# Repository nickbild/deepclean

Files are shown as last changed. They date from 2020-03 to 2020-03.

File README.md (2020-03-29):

# Deep Clean

Deep Clean watches a room and flags all surfaces as they are touched for special attention on the next cleaning to help prevent the spread of contagious disease.

One use case would be in a hospital room.  When a patient checks out, the cleaning service could view all surfaces that need special attention.

<p align="center">
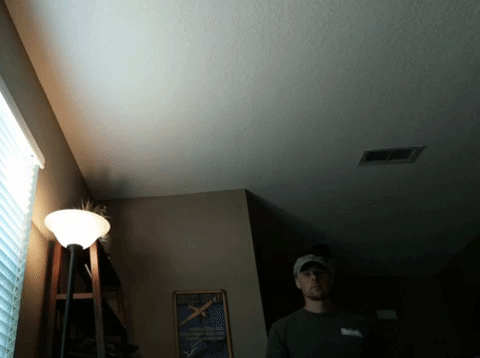
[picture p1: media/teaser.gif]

</p>

## How it Works

Deep Clean uses a stereo camera to detect the depth (z-coordinate) of an object of interest (e.g. a hand) in the video frame.  OpenPose is used to detect hand location (x,y-coordinates).  When a hand is at the same position and depth as another object in view (i.e. touching), that location is tracked.  An image can be generated showing all surfaces that have been touched ([script](https://github.com/nickbild/deepclean/blob/master/3dcam.py)).

### Camera

Camera options for the Xavier tend to be on the expensive side for a hobbyist, so I built my own from a pair of Raspberry Pi cameras.  To keep the cameras in the proper relative positions, I designed and 3D printed a [base](https://github.com/nickbild/deepclean/blob/master/3d_models/stero_cam_base.stl) and a [stabilizer](https://github.com/nickbild/deepclean/blob/master/3d_models/stereo_stabilizer.stl).

The Xavier does not have CSI connections for this type of camera, so I used a pair of Raspberry Pis to capture images ([script](https://github.com/nickbild/deepclean/blob/master/remote_cam.py)) when triggered via GPIO from the Xavier.  This is far from optimal, and shows itself in the low frame rate, but it works adequately on a budget.

The cameras were [calibrated](https://github.com/nickbild/deepclean/blob/master/camera_calibration/stereo_calibration.py) (individually, and in pair) in OpenCV using a printed chessboard pattern:

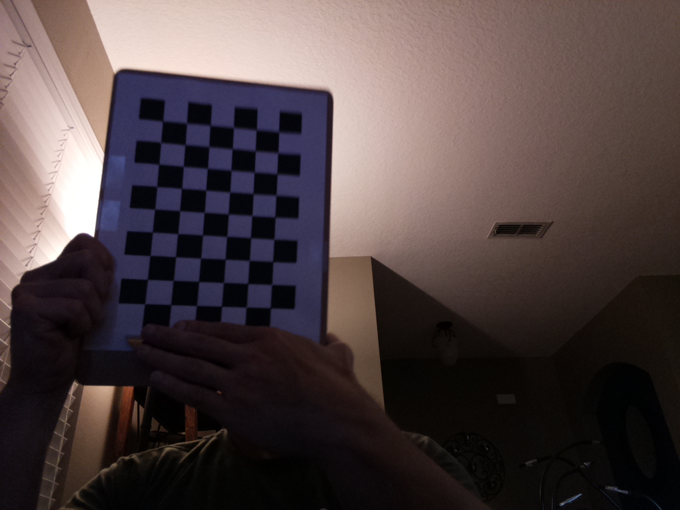
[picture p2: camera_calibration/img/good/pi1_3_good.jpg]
chessboard


## Media

YouTube Video:  
https://www.youtube.com/watch?v=Qy8Ks7UTtrA

Full setup:  
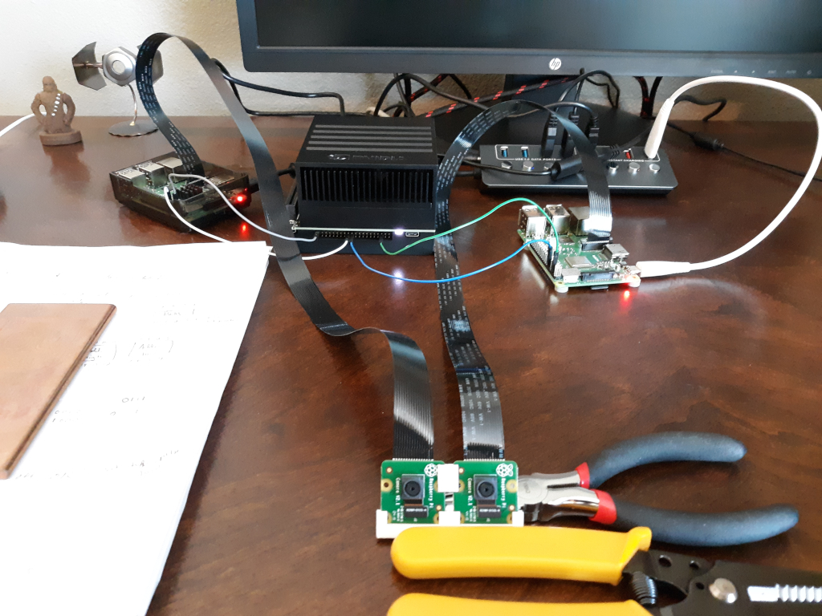
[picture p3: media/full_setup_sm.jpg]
Full Setup


Stereo Camera:  
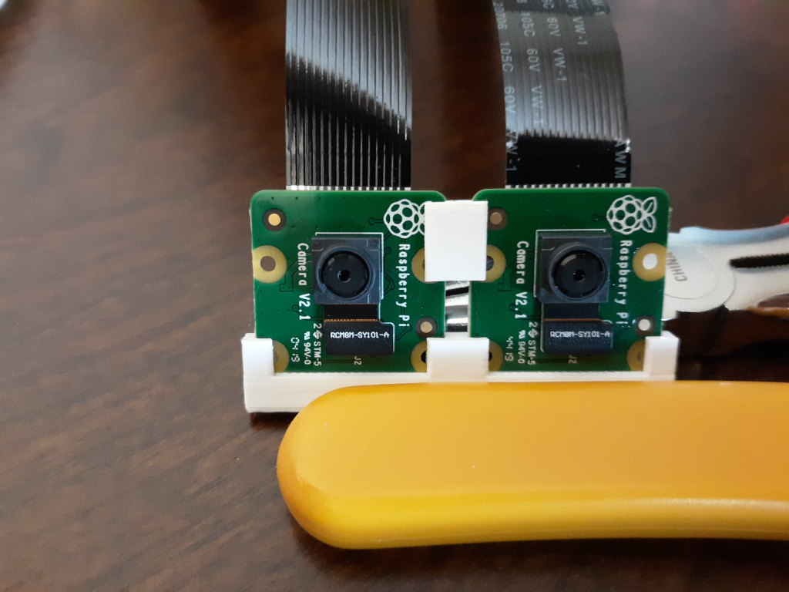
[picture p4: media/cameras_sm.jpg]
camera


## Bill of Materials

- 1 x NVIDIA Jetson AGX Xavier
- 2 x Raspberry Pi 3B+
- 2 x Raspberry Pi Camera v2
- 3D printer
- Miscellaneous wire

## Future Direction

With a higher budget, a more optimal version could be developed with an off the shelf stereo camera that can directly interface with the processing unit.  Using a custom-built stereo camera makes the system a little bit buggy at times, and capturing images on separate computers slows the frame rate substantially.

There is also room for adding additional detection techniques.  While I believe it's useful as is, it currently can't detect a cough or sneeze, for example, which can also contaminate surfaces.

## About the Author

[Nick A. Bild, MS](https://nickbild79.firebaseapp.com/#!/)

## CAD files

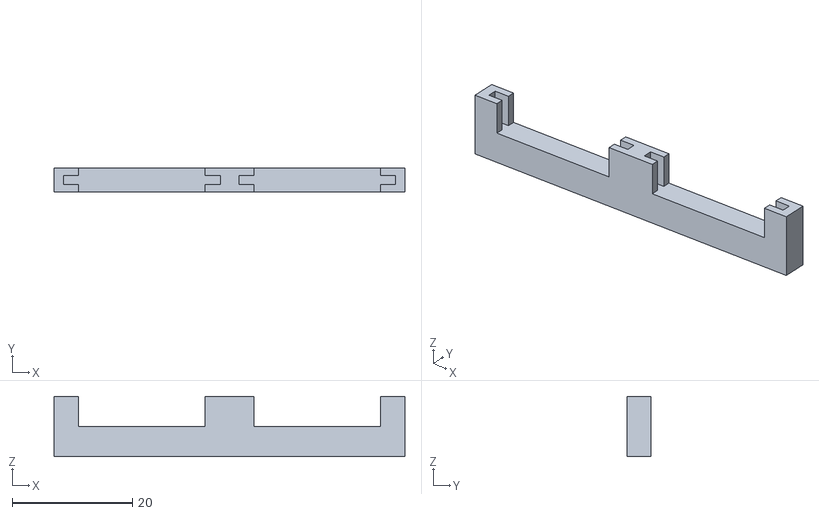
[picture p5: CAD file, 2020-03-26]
3d_models/stero_cam_base.stl
58.3 x 4.00 x 10.0

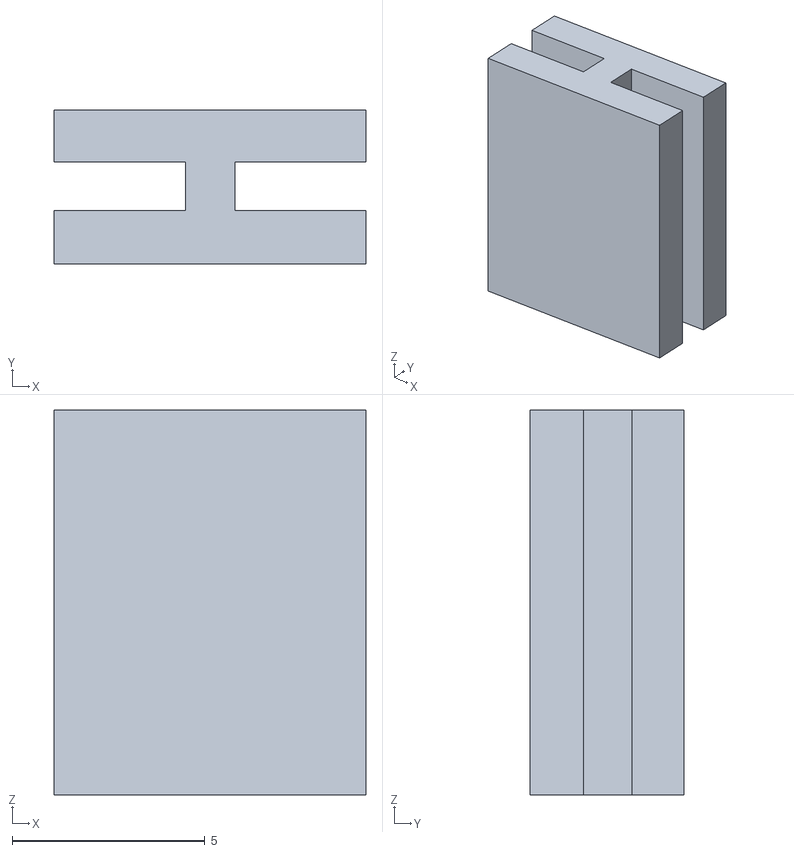
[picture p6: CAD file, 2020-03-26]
3d_models/stereo_stabilizer.stl
8.09 x 4.00 x 10.0

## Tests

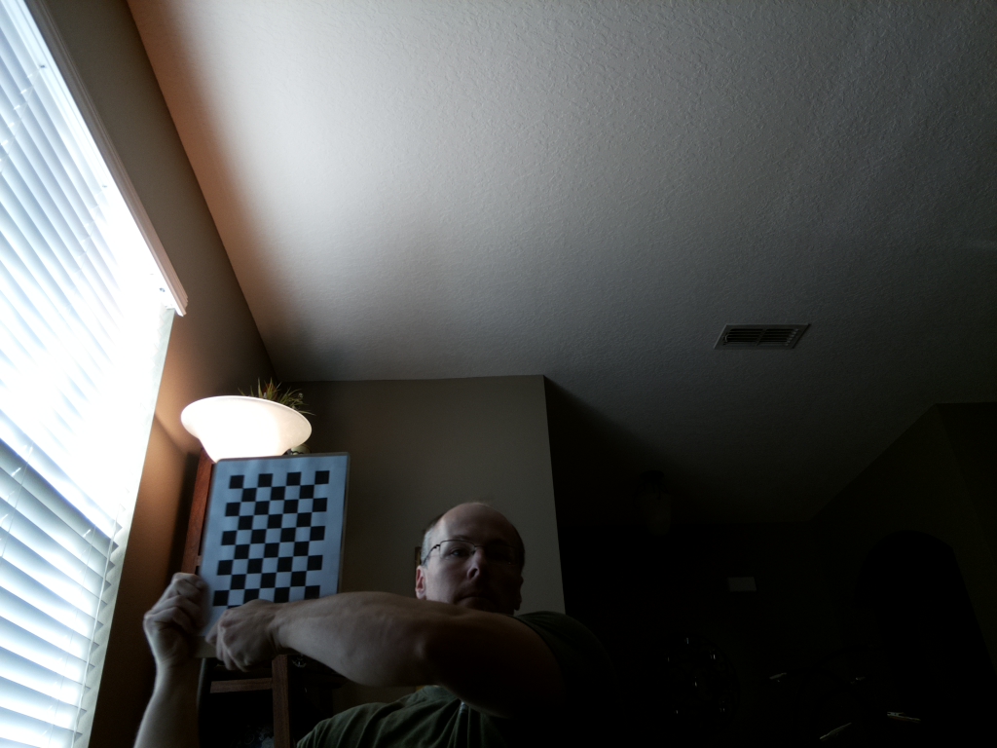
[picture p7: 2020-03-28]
camera_calibration/img/good/pi1_19_good.jpg

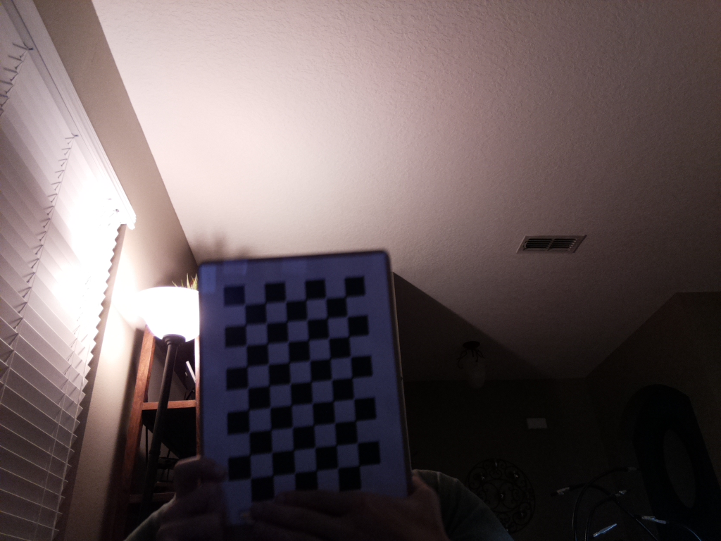
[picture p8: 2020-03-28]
camera_calibration/img/good/pi1_25_good.jpg

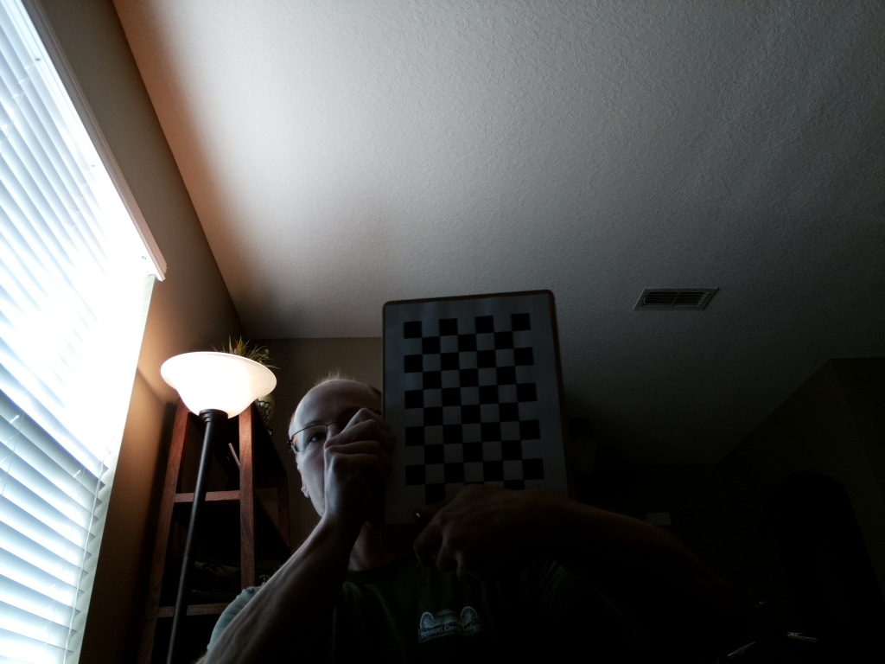
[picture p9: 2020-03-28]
camera_calibration/img/good/pi1_2_good.jpg

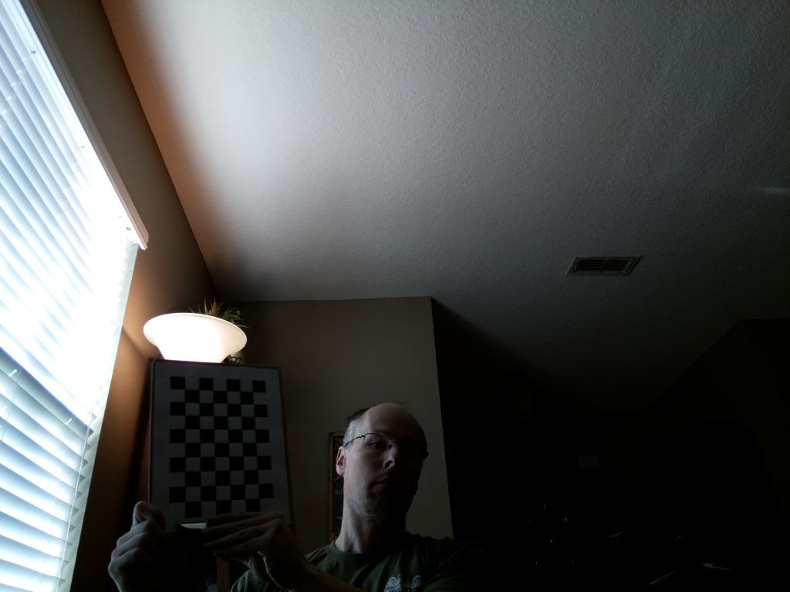
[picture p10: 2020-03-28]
camera_calibration/img/good/pi1_59_good.jpg

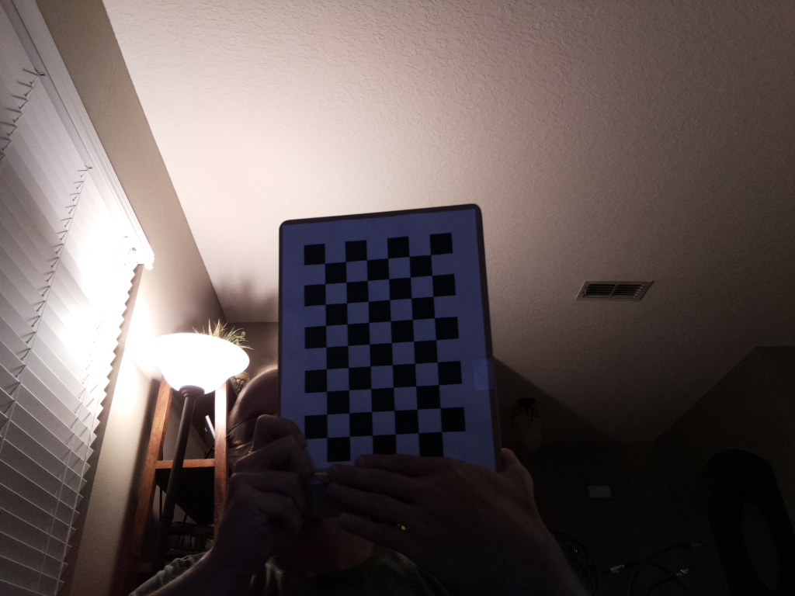
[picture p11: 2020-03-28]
camera_calibration/img/good/pi2_1_good.jpg

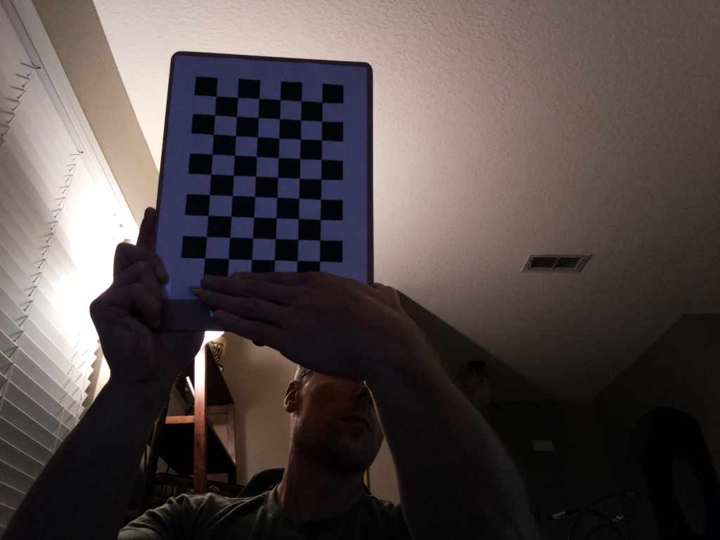
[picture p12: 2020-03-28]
camera_calibration/img/good/pi2_31_good.jpg

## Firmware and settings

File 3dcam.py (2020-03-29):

import Jetson.GPIO as GPIO
import time
from subprocess import call
import cv2
import numpy as np
import pyopenpose as op
import os


img_width = 1024
img_height = 768

max_disparity_o1 = 10
max_disparity_o2 = 8

output_pins = [22, 24]
params = dict()
params["model_folder"] = "/home/nick/software/openpose/openpose/models/"

GPIO.setmode(GPIO.BOARD)

for output_pin in output_pins:
    GPIO.setup(output_pin, GPIO.OUT, initial=GPIO.LOW)

cmds = ["scp pi@192.168.1.170:/home/pi/deepclean/pi.jpg pi1.jpg",
        "scp pi@192.168.1.171:/home/pi/deepclean/pi.jpg pi2.jpg"]
FNULL = open(os.devnull, 'w')

opWrapper = op.WrapperPython()
opWrapper.configure(params)
opWrapper.start()

# Load stereo calibration data.
calibration = np.load("camera_calibration/stereo_calibration.npz", allow_pickle=False)
imageSize = tuple(calibration["imageSize"])
leftMapX = calibration["leftMapX"]
leftMapY = calibration["leftMapY"]
leftROI = tuple(calibration["leftROI"])
rightMapX = calibration["rightMapX"]
rightMapY = calibration["rightMapY"]
rightROI = tuple(calibration["rightROI"])

trackLo1 = []
trackLo2 = []
trackRo1 = []
trackRo2 = []
vi = 0


def drawTrail(trail, img):
    if len(trail) < 2:
        return img

    for i in range(1, len(trail)):
        img = cv2.line(img, (trail[i-1][0], trail[i-1][1]), (trail[i][0], trail[i][1]), (0, 0, 255), 15)

    return img


while True:
    # Capture images from Raspberry Pis.
    for output_pin in output_pins:
        GPIO.output(output_pin, GPIO.HIGH)
        time.sleep(0.001)
        GPIO.output(output_pin, GPIO.LOW)

    time.sleep(0.1)

    # Retrieve images from Raspberry Pis.
    for cmd in cmds:
        call(cmd.split(" "), stdout=FNULL)

    # Rectify/analyze stereo images.
    imgL = cv2.imread('pi2.jpg')
    imgR = cv2.imread('pi1.jpg')
    stereo = cv2.StereoSGBM_create(numDisparities=16, blockSize=1)

    fixedL = cv2.remap(imgL, leftMapX, leftMapY, cv2.INTER_LINEAR)
    fixedR = cv2.remap(imgR, rightMapX, rightMapY, cv2.INTER_LINEAR)

    grayL = cv2.cvtColor(fixedL, cv2.COLOR_BGR2GRAY)
    grayR = cv2.cvtColor(fixedR, cv2.COLOR_BGR2GRAY)

    stereo.setMinDisparity(-2)
    stereo.setSpeckleRange(2)
    stereo.setSpeckleWindowSize(5)

    disparity = stereo.compute(grayL, grayR)

    #cv2.imwrite('left.jpg', grayL)
    #cv2.imwrite('right.jpg', grayR)

    # Determine body position.
    datum = op.Datum()
    datum.cvInputData = fixedL
    opWrapper.emplaceAndPop([datum])

    try:
        # Wrist location.
        #print("R wrist: {}".format(datum.poseKeypoints[0][4])) # Right wrist [x, y, score].
        #print("L wrist: {}".format(datum.poseKeypoints[0][7])) # Left wrist [x, y, score].

        # Raw / mean disparity in region.
        xR = int(datum.poseKeypoints[0][4][0])
        yR = int(datum.poseKeypoints[0][4][1])
        if (xR > 96 and xR < 231 and yR > 500) or (xR > 367 and xR < 489 and yR > 615):
            #print("Right ++++")
            #print(disparity[xR][yR])
            disparityLwrist = disparity[xR-20:xR+20, yR-20:yR+20]
            #print(disparityLwrist.mean())

            # Remember past locations.
            if disparityLwrist.mean() < max_disparity_o1:
                if (xR > 96 and xR < 231 and yR > 500):
                    trackRo1.append((xR-25, yR))
                else:
                    trackRo2.append((xR-25, yR))

        xL = int(datum.poseKeypoints[0][7][0])
        yL = int(datum.poseKeypoints[0][7][1])
        if (xL > 96 and xL < 231 and yL > 500) or (xL > 367 and xL < 489 and yL > 615):
            #print("Left ----")
            #print(disparity[xL][yL])
            disparityRwrist = disparity[xL-20:xL+20, yL-20:yL+20]
            #print(disparityRwrist.mean())

            # Remember past locations.
            if disparityRwrist.mean() < max_disparity_o2:
                if (xL > 96 and xL < 231 and yL > 500):
                    trackLo1.append((xL, yL))
                else:
                    trackLo2.append((xL, yL))

        # Draw wrist circles on image.
        #disparity = cv2.circle(disparity, (xR, yR), 20, (255, 0, 0), 2)
        #disparity = cv2.circle(disparity, (xL, yL), 20, (255, 0, 0), 2)

        # Plot past points.
        fixedL = drawTrail(trackLo1, fixedL)
        fixedL = drawTrail(trackLo2, fixedL)
        fixedR = drawTrail(trackRo1, fixedL)
        fixedR = drawTrail(trackRo2, fixedL)

    except:
        print("No human detected.")

    # View disparity map.
    #cv2.imwrite('result_distance.jpg', disparity)

    cv2.imwrite('left.jpg', fixedL)
    cv2.imwrite('video/left_{}.jpg'.format(vi), fixedL)
    vi += 1

    # View annotated pose image.
    # newImage = datum.cvOutputData[:, :, :]
    # cv2.imwrite("result_pose.jpg", newImage)

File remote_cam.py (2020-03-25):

import RPi.GPIO as GPIO
import picamera
import time
import os


input_pin = 12
GPIO.setmode(GPIO.BOARD)
GPIO.setup(input_pin, GPIO.IN)

high = False
low = False

with picamera.PiCamera() as camera:
    time.sleep(2)
    
    camera.resolution = (1024,768)
    camera.rotation = 180
    camera.capture('dummy.jpg')
    
    while True:
        if GPIO.input(input_pin) == 1:
            high = True

        if high and GPIO.input(input_pin) == 0:
            low = True

        if high and low:
            camera.capture('next.jpg')
            high = False
            low = False
            os.rename('next.jpg', 'pi.jpg')

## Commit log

2020-03-25 Add remote camera capture.
2020-03-26 Add 3D printer models.
    [stereo_stabilizer.stl, stero_cam_base.stl]
2020-03-27 Initial camera calibration code.
2020-03-27 Swap camera order.
2020-03-28 Tweak calibration.
2020-03-28 Fix individual calibrations.
2020-03-28 Fix stereo calibration.
2020-03-28 Track calibration data.
